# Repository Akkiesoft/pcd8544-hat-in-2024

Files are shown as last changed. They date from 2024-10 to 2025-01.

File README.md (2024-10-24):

# 令和6年最新版 PCD8544 HAT

PCD8544 (a.k.a. Nokia5110) ディスプレイをRaspberry Piで使用するための拡張ボードです。84x48しかないレトロなモノクロLCDでグラフィック表示を楽しんでみませんか？

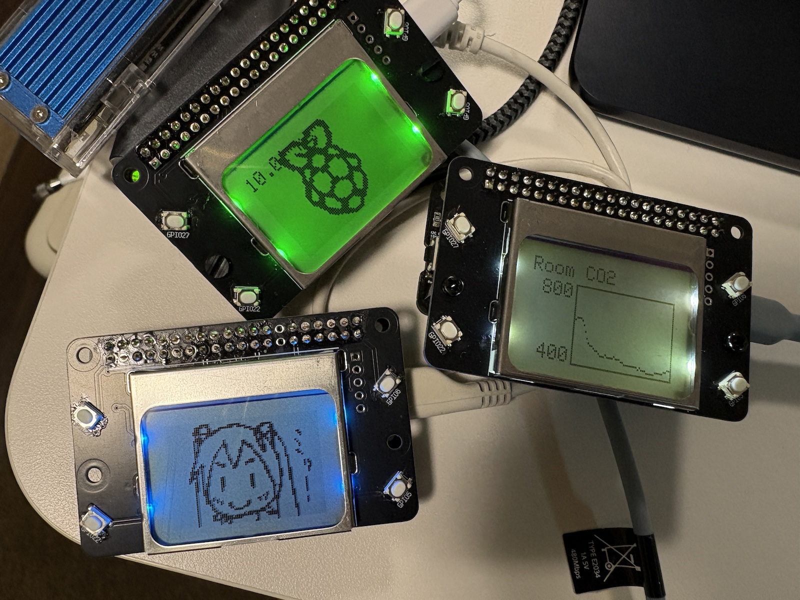
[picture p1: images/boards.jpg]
基板写真


## 特徴

* Raspberry Piの標準的なSPIピンに配線
* GPIOで制御可能なバックライト
* uHAT規格のマウントホールを用意 (ボードサイズはuHATよりももう少し大きいです)
* 4つのボタンを配置

## サンプルスクリプト

サンプルスクリプトはCircuitPythonで記述されています。

* pcd8544_demo.py
    * 基本的なデモスクリプトです
    * 左上のボタンを押すとバックライトのオン・オフ切り替え
    * 左下のボタンを押すとグラフ表示ライブラリのサンプルを表示
    * 右上と右下のボタンを押すと画像データを表示

## ライブラリ

いずれもpcd8544_demo.pyで使用例が確認できます。

* draw_img
    * フレームバッファ形式に合わせた画像の配列データを描画します
* draw_graph
    * グラフを描画します

## ユーティリティスクリプト

* img_convert.py
    * 84x48の画像を、draw_imgライブラリで描画可能な配列形式に変換します

## 基板データ

TBD

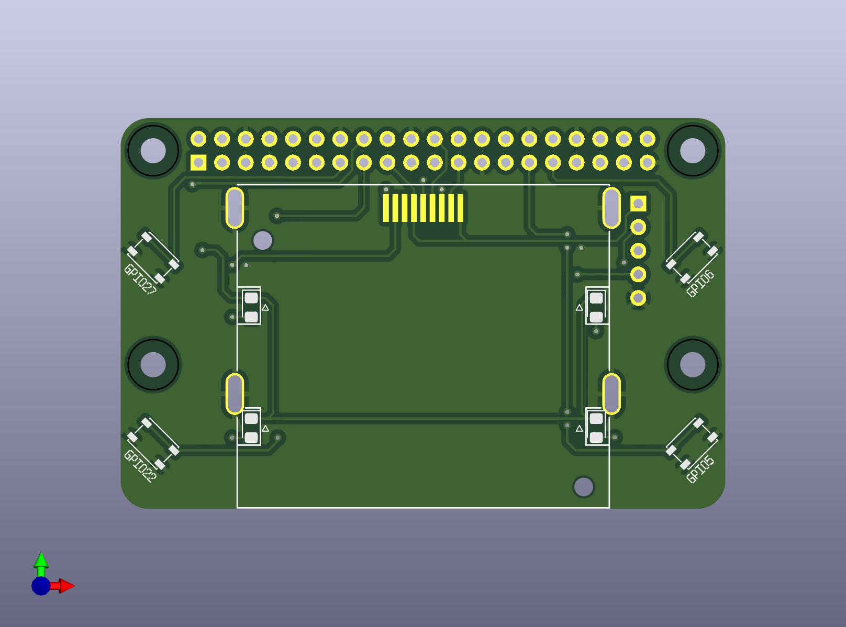
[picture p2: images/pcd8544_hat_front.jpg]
基板表面

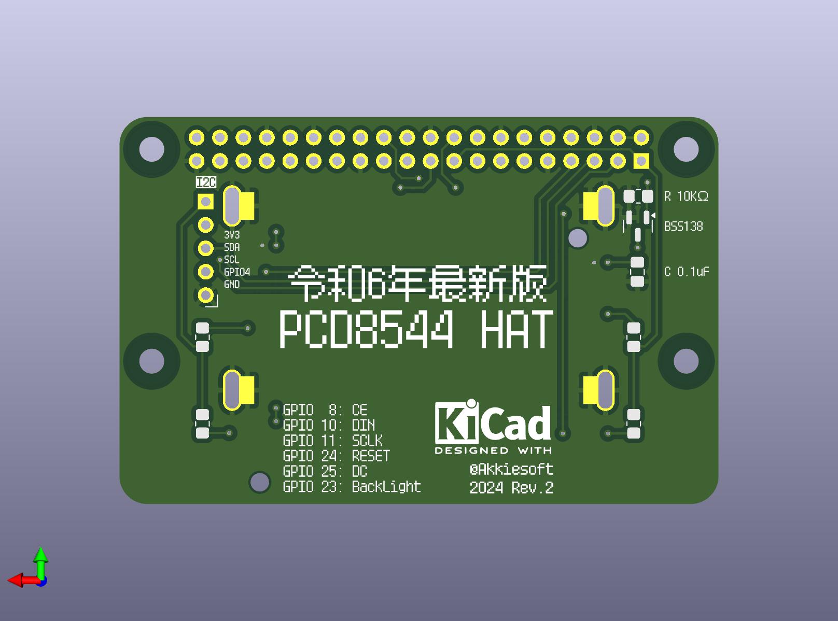
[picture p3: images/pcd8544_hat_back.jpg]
基板裏面


## 部品リスト

* 1x BSS138
    * https://akizukidenshi.com/catalog/g/g111627/
* 1x 0.1uF 積層セラミックコンデンサー
    * https://akizukidenshi.com/catalog/g/g117576/
* 1x 10KΩ表面実装抵抗 (2012/0805サイズ)
* 4x 330Ω表面実装抵抗 (2012/0805サイズ)
    * LED用。LEDに合わせて適宜変更してください
* 4x 表面実装LED (2012/0805サイズ)
    * https://akizukidenshi.com/catalog/g/g106423/
    * https://akizukidenshi.com/catalog/g/g106424/
    * https://akizukidenshi.com/catalog/g/g106425/
* 4x 表面実装ボタン (3mm * 4mm * 2.5mm)
    * https://aliexpress.com/item/1005004888773791.html
* PCD8544
    * https://aliexpress.com/item/1005005594822679.html

## Used libraries and footprint

* [KiCad footprint for Nokia 5110 LCD](https://hackaday.io/page/3427-kicad-footprint-for-nokia-5110-lcd)
    * by sgreg, MIT License

## License

令和6年最新版 PCD8544 HAT (PCD8544 HAT in 2024)

2024 @Akkiesoft, MIT License

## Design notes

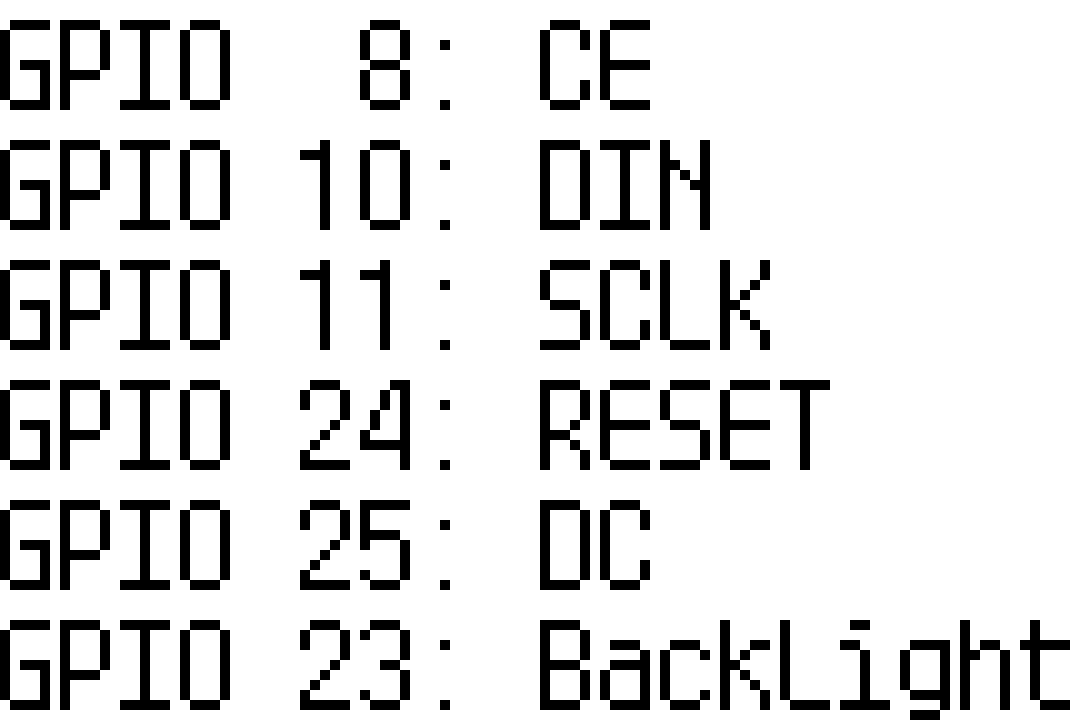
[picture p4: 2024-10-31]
pcd8544-hat-in-2024/silk-images/gpio-list.png

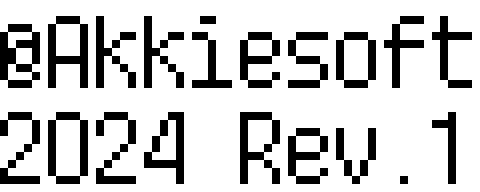
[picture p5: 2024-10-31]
pcd8544-hat-in-2024/silk-images/copyright.png

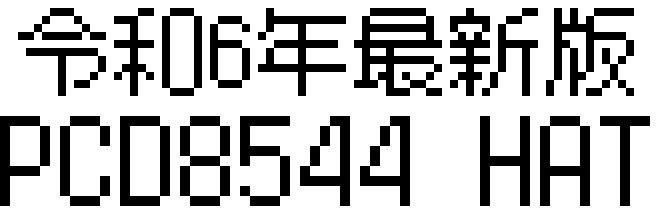
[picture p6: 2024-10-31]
pcd8544-hat-in-2024/silk-images/name.png

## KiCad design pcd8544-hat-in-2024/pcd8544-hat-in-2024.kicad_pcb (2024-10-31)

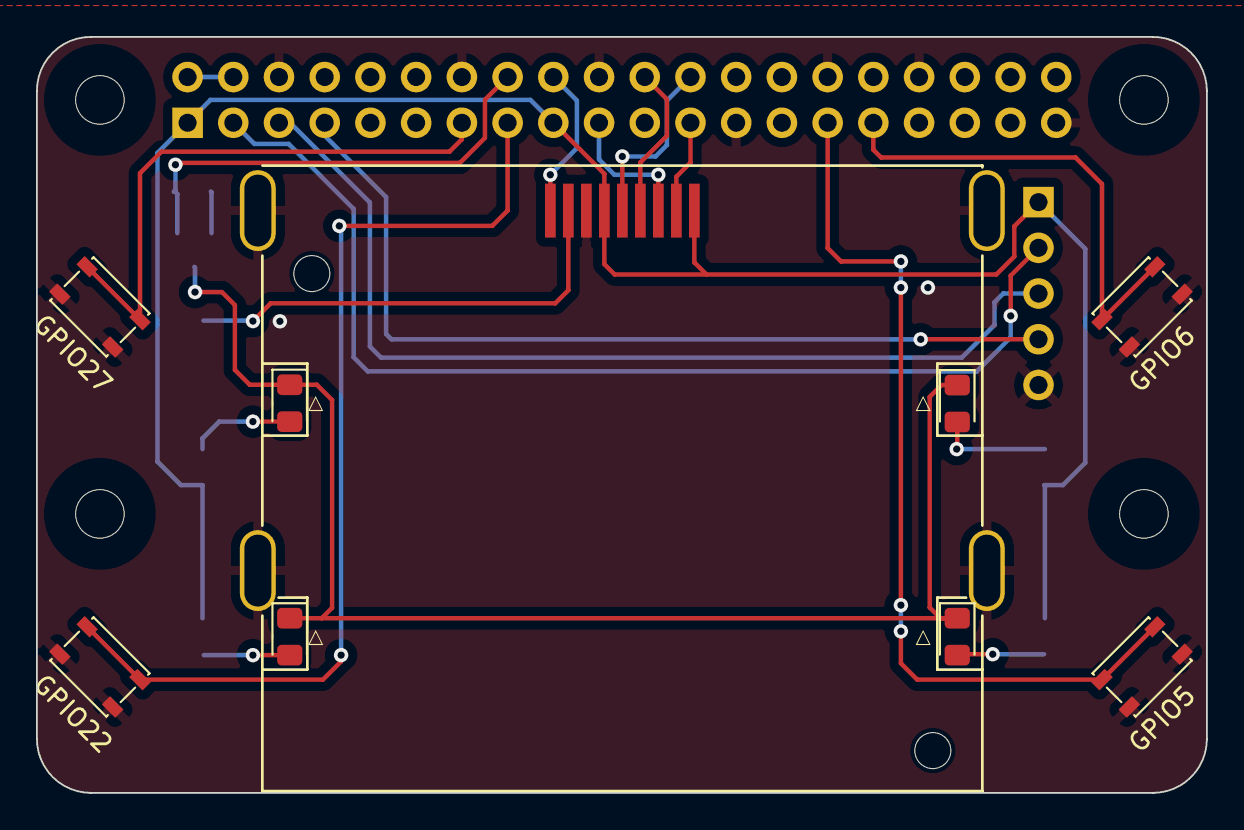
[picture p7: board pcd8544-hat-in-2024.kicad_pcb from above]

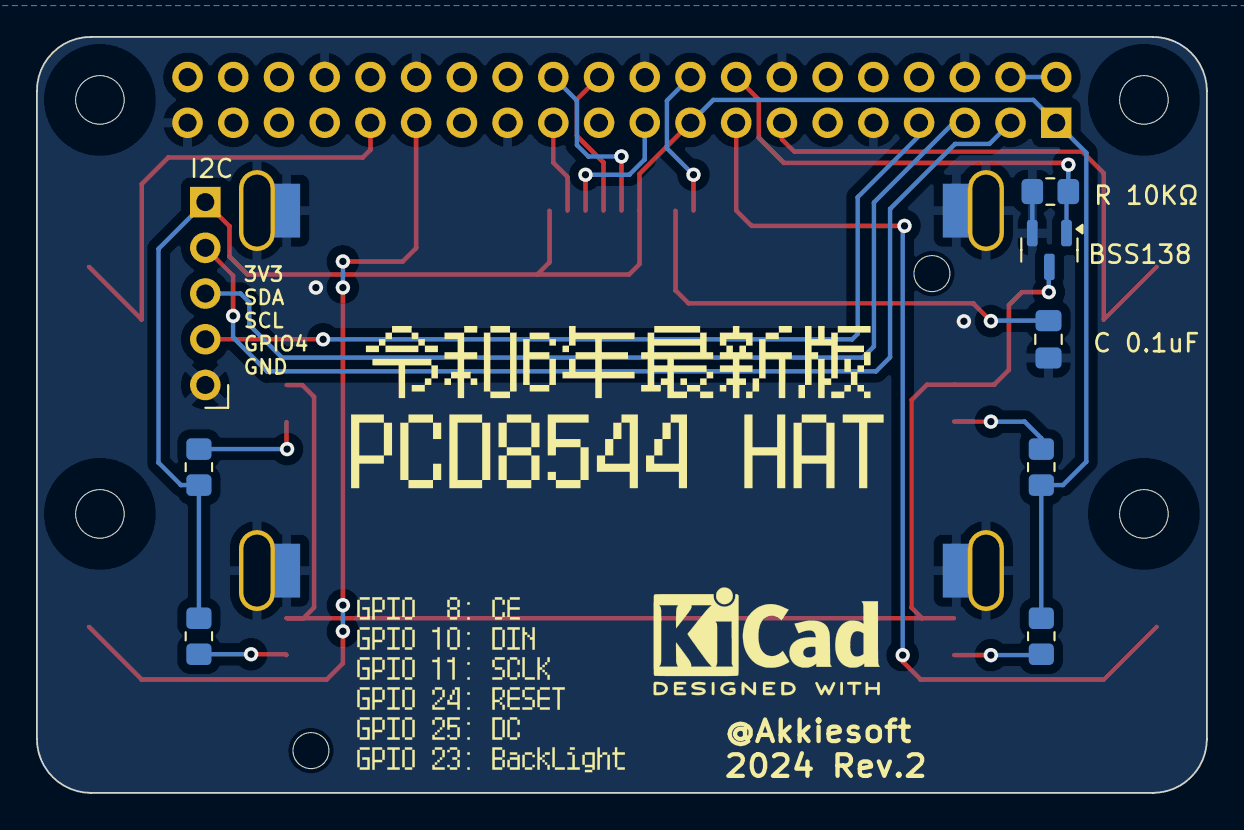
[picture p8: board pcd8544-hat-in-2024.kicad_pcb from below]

Board: 2 copper layers, 65.0 x 42.0 mm, 22 parts (9 on the bottom side), 22 nets.

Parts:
C1: C 0.1uF; C_0805_2012Metric_Pad1.18x1.45mm_HandSolder
D1, D2, D3, D4: LED; LED_0805_2012Metric_Pad1.15x1.40mm_HandSolder
GPIO5, GPIO6, GPIO22, GPIO27: SW_Push; SW_SPST_PTS810
H1, H2, H3, H4: MountingHole; MountingHole_2.7mm_M2.5_uHAT_RPi
J1: Raspberry_Pi_2_3; PinSocket_2x20_P2.54mm_Vertical_Centered_Anchor
J2: Conn_01x05_Socket; PinHeader_1x05_P2.54mm_Horizontal
Q2: BSS138; SOT-23
R1, R2, R3, R4: R; R_0805_2012Metric_Pad1.20x1.40mm_HandSolder
R 10KΩ: R; R_0805_2012Metric_Pad1.20x1.40mm_HandSolder
U1: Nokia_5110_LCD; Nokia_5110-3310_LCD

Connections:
+3V3: J1.1 (3V3), J1.17 (3V3), J2.5, R1.2, R2.2, R3.2, R4.2, U1.4 (OSC), U1.9 (VCC)
+5V: J1.2 (5V), J1.4 (5V)
BTN_1: GPIO22.1, J1.15 (GPIO22)
BTN_2: GPIO27.1, J1.13 (GPIO27)
BTN_3: GPIO5.1, J1.29 (GCLK1/GPIO5)
BTN_4: GPIO6.1, J1.31 (GCLK2/GPIO6)
GND: C1.2, GPIO5.2, GPIO6.2, GPIO22.2, GPIO27.2, J1.6 (GND), J1.9 (GND), J1.14 (GND), J1.20 (GND), J1.25 (GND), J1.30 (GND), J1.34 (GND), J1.39 (GND), J2.1, Q2.2 (S), R 10KΩ.2, U1.3 (GND)
unnamed: D1.2 (A), R1.1
unnamed: D1.1 (K), D2.1 (K), D3.1 (K), D4.1 (K), Q2.3 (D)
unnamed: D2.2 (A), R2.1
unnamed: D3.2 (A), R3.1
unnamed: D4.2 (A), R4.1
unnamed: J1.7 (GCLK0/GPIO4), J2.2
unnamed: J1.16 (GPIO23), Q2.1 (G), R 10KΩ.1
unnamed: J1.18 (GPIO24), U1.1 (~RST)
unnamed: J1.22 (GPIO25), U1.6 (D/~C)
unnamed: J1.19 (MOSI0/GPIO10), U1.7 (SDIN)
unnamed: J1.23 (SCLK0/GPIO11), U1.8 (SCLK)
unnamed: J1.5 (SCL/GPIO3), J2.3
unnamed: J1.3 (SDA/GPIO2), J2.4
unnamed: J1.24 (~CE0/GPIO8), U1.5 (~SCE)
unnamed: C1.1, U1.2 (VOUT)

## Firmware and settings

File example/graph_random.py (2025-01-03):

# Graph demo

"""
Required libralies and font:
* adafruit_framebuf
* adafruit_pcd8544
* font5x8.bin
"""

# Choose your environment:
# rpi: Raspberry Pi SBC
# uhp: Raspberry Pi Pico with uHAT Porter Pico
# uhp_r2: Raspberry Pi Pico with uHAT Porter Pico Rev.2
from config import pcd8544_config
config = pcd8544_config("uhp")

from digitalio import DigitalInOut, Direction
import time
import random
# display
from busio import SPI
import adafruit_pcd8544

# my own libraries and images
from lib.draw_graph import draw_graph

# 令和6年最新版 PCD8544 HAT
spi = SPI(clock=config.sck, MOSI=config.mosi)
dc = DigitalInOut(config.dc)
cs = DigitalInOut(config.cs)
reset = DigitalInOut(config.rst)

display = adafruit_pcd8544.PCD8544(spi, dc, cs, reset)
display.bias = 4
display.contrast = 60
display.fill(0)
display.show()

# Switch on backlight
backlight = DigitalInOut(config.light)
backlight.direction = Direction.OUTPUT
backlight.value = 1


# デフォルトのデータ
data = [50, 0, 1, 2, 3, 4, 5, 6, 7, 8, 9, 10, 20, 30, 40, 50, 60, 70, 80, 90, 99, 100, 80]

# グラフの作成    (         位置,  サイズ,最大最小値, データ)
graph = draw_graph(display, 20,15, 50,33, 45, 0, data)
graph.draw_graph()

# ラベル
display.text("Graph Sample", 6, 2, 1)
display.text(" 45", 0, 15, 1)
display.text("  0", 0, 40, 1)

display.show()

while True:
    # ランダムなデータを配列に追加
    data.append(random.randint(5, 45))
    # グラフサイズから溢れた古いデータは消す
    if 49 <= len(data):
        del data[0]
    # グラフを描画
    graph.draw_graph()
    time.sleep(0.1)

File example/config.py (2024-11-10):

import board

class pcd8544_config:
    def __init__(self, mode):
        self.mode = mode
        if self.mode == "rpi":
            self.__set_gpio_rpi()
        elif self.mode == "uhp":
            self.__set_gpio_uhp()
        elif self.mode == "uhp_r2":
            self.__set_gpio_uhp_r2()

    def __set_gpio_rpi(self):
        self.sck     = board.D11
        self.mosi    = board.D10
        self.dc      = board.D25
        self.cs      = board.D8
        self.rst     = board.D24
        self.light   = board.D23
        self.buttons = (board.D27, board.D22, board.D6, board.D5)
        self.int_pin = board.D4

    def __set_gpio_uhp(self):
        self.sck     = board.GP18
        self.mosi    = board.GP19
        self.dc      = board.GP10
        self.cs      = board.GP22
        self.rst     = board.GP6
        self.light   = board.GP7
        self.buttons = (board.GP9, board.GP8, board.GP12, board.GP11)
        self.int_pin = board.GP3

    def __set_gpio_uhp_r2(self):
        self.sck     = board.GP18
        self.mosi    = board.GP19
        self.dc      = board.GP10
        self.cs      = board.GP22
        self.rst     = board.GP9
        self.light   = board.GP8
        self.buttons = (board.GP6, board.GP7, board.GP12, board.GP11)
        self.int_pin = board.GP3

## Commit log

2024-10-31 add kicad data and garber data
    [pcd8544-hat-in-2024.kicad_pcb, pcd8544-hat-in-2024.kicad_sch]
2024-11-10 added variable to select boards
2024-11-10 add ds18b20 sample
2025-01-03 load ds18b20 module for pico in the if statement
